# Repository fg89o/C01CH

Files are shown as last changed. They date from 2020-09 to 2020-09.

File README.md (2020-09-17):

# DomDom - C01CH

## ¿Qué es es el proyecto C01CH?

-----

Este proyecto nació con la intención de crear un controlador para pantallas de acuario. Después de revisar otros proyectos anteriores a este nos dimos cuenta que todos ellos o se quedaban incompletos o abarcaban mucho más que la pantalla. Por ello se decidió hacer un equipo lo más completo posible pero centrándonos únicamente en las necesidades para controlar una pantalla de acuario.

## Características principales

-----

* Equipo económico (coste inferior a 10€)
* Corriente de tensión hasta 24V.
* 1 canal dimeable por control de corriente.

   Esta característica significa que en vez de apagar y encender el led muy muy rápido como hacen otros controladores (control por PWM) nosotros controlamos el brillo del led mediante el control de corriente. Esto permite un brillo inferior pero teniendo el led encendido el 100% del tiempo.

   Por otra parte, esta característica permite ser el equipo compatible con el 100% de pantallas que trabajan con un voltaje igual o inferior a  24V.

* Monitorización del consumo y de la potencia.
* Ajuste manual de la potencia que se mantendrá incluso depués de apagar el equipo.
* Programación de potencia en función de la hora con hasta 50 puntos de programación.
* Servicio NTP para configurar la fecha, hora y ajuste de horario verano/invierno de forma automática.
* Control para un ventilador externo.
* Calculo en tiempo real del espectro de nuestra pantalla. (Siempre que configuremos el tipo de leds que estamos usando)
* Conexión mediante WIFI.
* Equipo actualizable de forma remota mediante WIFI.
* Servidor web integrado para configurar el equipo desde cualquier dispositivo, utilizando únicamente un navegador web.

-----

## Lista de materiales

-----

Pongo los links donde yo he comprado las cosas porque me ha parecido un buen vendedor pero cabe recalcar que no tengo ningún acuerdo con las tiendas que aparecen.

| Componente | Cantidad | Precio Total| link |
| --- | ---: | ---:| ---- |
| ESP32 Devkit-C de 36 pines  | 1 | 3.66€| [link](https://es.aliexpress.com/item/32807887667.html?spm=a2g0s.9042311.0.0.1f6c63c0jkFGcQ) |
| Mini DC-DC | 1 | 0.43€| [link](https://es.aliexpress.com/item/32649396601.html?spm=a2g0s.9042311.0.0.1f6c63c0jkFGcQ) |
| MOSFET PWM 400W 15A | 1 | 0.67€| [link](https://es.aliexpress.com/item/32803005422.html?spm=a2g0s.9042311.0.0.274263c0MQxfmC) |
| INA219 | 1 | 1.08€| [link](https://es.aliexpress.com/item/33025643671.html?spm=a2g0s.9042311.0.0.1f6c63c0jkFGcQ) |
| XL4015 | 1 | 0.91€| [link](https://es.aliexpress.com/item/4001118651312.html?spm=a2g0s.9042311.0.0.1f6c63c0jkFGcQ) |
| Resistencia 507Ohms | 1 | 0.005€| [link](https://es.aliexpress.com/item/32953278667.html?spm=a2g0s.9042311.0.0.274263c0MQxfmC) |
| Cables varios | 1 | 1  € | [link](https://es.aliexpress.com/item/32965231797.html?spm=a219c.12010615.8148356.1.6921396csAn5Dh)|
| DC Power pin hembra | 3 | 0.28€| [link](https://es.aliexpress.com/item/32973509798.html?spm=a2g0s.9042311.0.0.1f6c63c0jkFGcQ) |
| Caja 3D | 1 | 3€| [link](./STL%20Caja/XL4015) |
| Tornillo 12mm M3 y tuerca | 1 | 0.20€ | |
-----

## Esquema de conexiones

-----

Una imagen vale más que mil palabras...

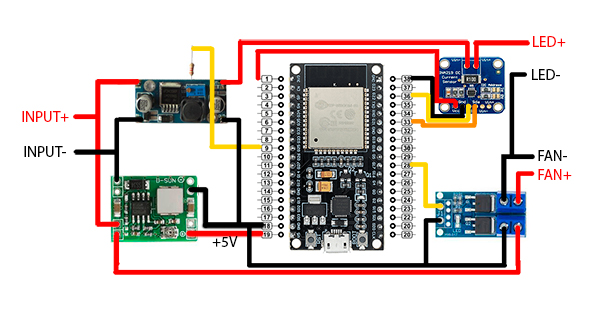
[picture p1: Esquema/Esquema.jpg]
Esquema


-----

## Firmware

-----

### Requisitos

* [NodeJS v12.18.3](https://nodejs.org/es/)
* [npm v6.14.6](https://www.npmjs.com/get-npm)
* [Visual studio code](https://code.visualstudio.com/download)
* [Platform IO](https://platformio.org/)
* [Vetur VS Code plugin](https://marketplace.visualstudio.com/items?itemName=octref.vetur)
* [C/C++ VS Code plugin](https://code.visualstudio.com/docs/languages/cpp)

### Compilacion

1. Tener instalados todos los requisitos mencionados anteriormente.
2. Clonar el repositorio
3. Abrir la carpeta "CH01CH UI" con el VS Code
4. Ejecutar en la terminal:

   ```javascript
   npm install
   ```

5. A continuación ejecutar:

   ```javascript
   npm run build
   ```

6. Abrir la carpeta "CH01CH fw" con el VS Code
7. Conectar el ESP32 por USB al ordenador
8. Ejecutar la opción "Task -> env:esp32dev -> Platform -> Upload Filesystem Image" o por terminal

   ```javascript
   platformio.exe run --target uploadfs --environment esp32dev
   ```

9. A) (opcional) Opcionalmente podemos modificar el fichero configuration.h con los datos de nuestra wifi para que se conecte directamente

   ```c
   // Define la red wifi a la que intetara conectase por defecto
   #define WIFI_STA_SSID_NAME "NOMBRE_DEL_WIFI"

   // Define el password de la red wifi por defecto
   #define WIFI_STA_PASSWORD "CONTRASEÑA"
   ```

10. B) Ejecutar la opción "Task -> General -> Upload" o por terminal

   ```javascript
   platformio.exe run --target upload
   ```

11. Comprobar que todo funciona correctamente:

* Si hemos configurado nuestro wifi en el paso 9.A solamente tendremos que acceder a http://C01CH.local.
* En caso de que no lo hayamos configurado debemos conectarnos al wifi creado por el equipo, que el SSID y será C01CH y después acceder a http://C01CH.local

# Soporte

Todo el que necesite soporte lo puede hacer bien a través de las issue de github de este proyecto o, los que dispongan de acceso, a través de este post en el que también se está siguiendo el proyecto.

# Agradecimientos

Muchas gracias a toda la gente que ha participado en este proyecto, bien con ideas, críticas que ayudan a crecer o de cualquier otro modo. En especial mencionar a todo el foro de [AcuariofiliaMadrid](https://acuariofiliamadrid.org/index.php) por el soporte dado y porque gracias al gran foro que mantienen he podido aprender los conocimientos necesarios para desarrollar satisfactoriamente este proyecto.

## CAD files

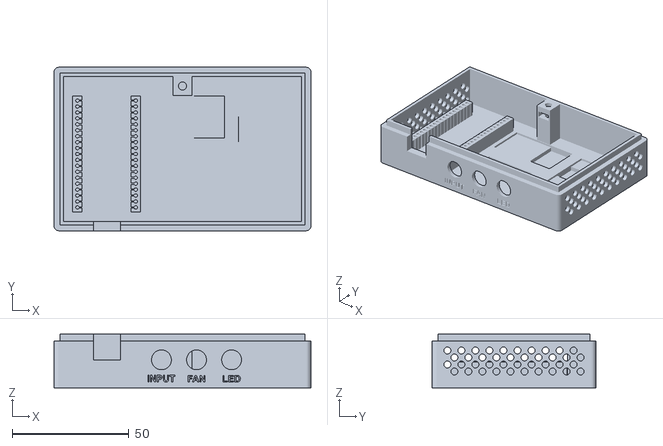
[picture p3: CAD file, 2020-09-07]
STL Caja/LM2596/Base LM2596.stl
110.0 x 70.0 x 23.0

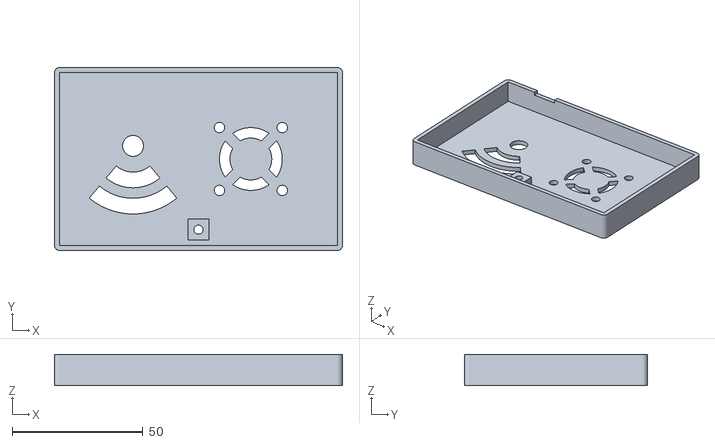
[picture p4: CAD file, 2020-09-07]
STL Caja/LM2596/Tapa LM2596.stl
110.0 x 70.0 x 12.0

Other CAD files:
STL Caja/XL4015/Base XL4015.stl
STL Caja/XL4015/Tapa XL4015.stl

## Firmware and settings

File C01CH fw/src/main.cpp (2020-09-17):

/**
 * DomDom Firmware
 * Copyright (c) 2020 DomDomFirmware
 *

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
 */

#include <Arduino.h>
#include <EEPROM.h>
#include <Wire.h>
#include "configuration.h"
#include "statusLedControl/statusLedControl.h"
#include "channel/channel.h"
#include "wifi/WiFi.h"
#include "rtc/rtc.h"
#include "webServer/webServer.h"
#include "EEPROMHelper.h"
#include "channel/ScheduleMgt.h"
#include "fan/fanControl.h"
#include "log/logger.h"

void initEEPROM()
{
  
  DomDomLogger.log(DomDomLoggerClass::LogLevel::info, "MAIN", "Iniciando EEPROM con %d bytes", EEPROM_SIZE+EEPROM_INA_SIZE);
  bool init = false;
  int err_count = 0;
  while(err_count<EEPROM_INIT_RETRIES && !init)
  {
      init = EEPROM.begin(EEPROM_SIZE+EEPROM_INA_SIZE);
      if (!init)
      {
          err_count++;
          Serial.print(".");
          delay(200);
      }
  }

  EEPROMCheck();

}

void setup()
{
  Serial.begin(BAUDRATE);

  DomDomLogger.log(DomDomLoggerClass::LogLevel::info, "MAIN", "C01CH Firmware | Copyright (c) 2020 Óscar Fernández");

  // Inicializamos la eeprom
  initEEPROM();

  // Inicializamos el control del led de estado
  DomDomStatusLedControl.begin();
  DomDomStatusLedControl.blinkDelay = 2000;
  DomDomStatusLedControl.blinkInfinite();
  DomDomStatusLedControl.blinkDelay = 1000;

  // Inicializa el wifi
  DomDomWifi.begin();
  // Si llegamos aqui y no estamos conectados resetamos en 5 segundos
  if (!DomDomWifi.isConnected())
  {
    int seg = 5;
    DomDomLogger.log(DomDomLoggerClass::LogLevel::error, "MAIN", "Equipo sin conexion. Se reiniciará en %d segundos!", seg);
    delay(seg * 1000);
    ESP.restart();
  }

  // Configuramos el RTC
  DomDomRTC.load();
  // Si tenemos conexion a internet inicamos todos los servicios
  if (DomDomWifi.getMode() == 1)
  {
    // Inicializacion del RTC
    DomDomRTC.begin();
  } else {
    DomDomLogger.log(DomDomLoggerClass::LogLevel::warn, "MAIN", "Equipo sin conexion no se establecera la hora RTC");
  }

  // Iniciamos el servidor web
  DomDomWebServer.begin();

  // configuramos el canal
  DomDomChannel.loadFromEEPROM();
 // Iniciamos el canal
  DomDomChannel.begin();  

  // Puntos de programacion
  DomDomScheduleMgt.load();
  
  // Iniciamos la programacion
  if (EEPROM.readBool(EEPROM_SCHEDULE_STATUS_ADDRESS))
  {
      DomDomScheduleMgt.begin();
  }else{
    DomDomChannel.setTargetmA(DomDomChannel.target_mA);
  }

  // Ventilador
  DomDomFanControl.begin();
}

void loop()
{

  /************************************************
   * 
   *  EN ESTE PROYECTO EL LOOP() ESTARA VACIO 
   *  YA QUE APROVECHAMOS LAS TASK PARA SACARLE
   *  EL MAXIMO PARTIDO A LOS DOS CORES DEL ESP.
   * 
   * *********************************************/

}

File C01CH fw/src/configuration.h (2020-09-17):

#pragma once

#ifndef DOMDOM_GLOBAL_CONFIGURACION_h
#define DOMDOM_GLOBAL_CONFIGURACION_h

#define DEBUG

// Datos del proyecto
#define PROJECT_VER     1.1
#define PROJECT_MODEL   "C01CH"

//===========================================================================
//============================ Serial Settings  =============================
//===========================================================================
// Define la velocidad de comunicación del puerto COM
#define BAUDRATE 9600

//===========================================================================
//============================ STATUS LED CONTROL  ==========================
//===========================================================================

#define LED_STATUS_RESOLUTION   10
#define LED_STATUS_CHANNEL      10
#define LED_STATUS_PIN          2
#define LED_STATUS_BLINK_DELAY  100

//===========================================================================
//============================ WIFI Settings  ===============================
//===========================================================================

// Define la red wifi a la que intetara conectase por defecto
#define WIFI_STA_SSID_NAME "" 

// Define el password de la red wifi por defecto
#define WIFI_STA_PASSWORD ""

// Numero de intentos para conectar el wifi
#define WIFI_NUM_RETRIES 3

// Tiempo de espera entre intentos
#define WIFI_CONNECTION_LATENCY 5000

// Nombre del AP que se creara para conectarse al equipo (32 digitos max.)
#define WIFI_AP_SSID_NAME "C01CH"

// Contraseña para el AP (entre 8 y 63 max.)
#define WIFI_AP_PASSWORD ""

// Numero maximo de conexiones al punto de acceso ( 4 max. )
#define WIFI_AP_MAX_CONNECTIONS 4

// Canal (entre 1 y 13)
#define WIFI_AP_CHANNEL 6

// Estado del ssid. 1 = HIDDEN ; 0 = BROADCAST
#define WIFI_AP_HIDDEN 0

//===========================================================================
//============================ mDNS SECTION =================================
//===========================================================================

#define MDNS_ENABLED 1

// Nombre mDNS para localizar el equipo
#define MDNS_HOSTNAME "C01CH"

//===========================================================================
//============================ CHANNELS SECTION =============================
//===========================================================================

#define CHANNEL_SIZE                    1
#define CHANNEL_RESOLUTION              8
#define CHANNEL_MAX_LEDS_CONFIG         10
#define CHANNEL_CURRENT_PIN             { 25 }
#define CHANNEL_BUS_REFRESH_INTERVAL    10000
#define CHANNEL_PERCENTAGE_MIN_STEP     5

//===========================================================================
//============================ FAN SECTION =============================
//===========================================================================
#define FAN_PWM_PIN                     17
#define FAN_PWM_RESOLUTION              10
#define FAN_PWM_CHANNEL                 12

//===========================================================================
//===================== RTC Y  NTP SECTION ==================================
//===========================================================================

#define RTC_BEGIN_ATTEMPS       3
#define RTC_BEGIN_ATTEMPS_DELAY 200

#define NTP_ENABLED             1
#define NTP_SERVERNAME          "pool.ntp.org"
#define NTP_TIMEZONE            "Europe/Madrid"
#define NTP_POSIX_TIMEZONE      "CET-1CEST,M3.5.0,M10.5.0/3"
#define NTP_DELAY_ON_FAILURE    10000
#define NTP_DELAY_ON_SUCCESS    3600000

//===========================================================================
//============================ EEPROM SECTION ===============================
//===========================================================================

#define EEPROM_SIZE                             EEPROM_FAN_ENABLED_ADDRESS
#define EEPROM_INIT_RETRIES                     10
#define EEPROM_INA_SIZE                         512

#define EEPROM_STA_SSID_NAME_ADDRESS            4
#define EEPROM_SSID_NAME_LENGTH                 32
#define EEPROM_STA_PASSWORD_ADDRESS             EEPROM_STA_SSID_NAME_ADDRESS + EEPROM_SSID_NAME_LENGTH
#define EEPROM_STA_PASSWORD_LENGTH              64

#define EEPROM_CHANNEL_FIRST_ADDRESS            EEPROM_STA_PASSWORD_ADDRESS +  EEPROM_STA_PASSWORD_LENGTH
#define EEPROM_CHANNEL_MEMORY_SIZE              16
#define EEPROM_CHANNEL_LED_MEMORY_SIZE          7
#define EEPROM_CHANNEL_LED_COUNT                10

#define EEPROM_MAX_SCHEDULE_POINTS              50
#define EEPROM_SCHEDULE_STATUS_ADDRESS          EEPROM_CHANNEL_FIRST_ADDRESS + EEPROM_CHANNEL_MEMORY_SIZE + (EEPROM_CHANNEL_LED_MEMORY_SIZE * EEPROM_CHANNEL_LED_COUNT)
#define EEPROM_SCHEDULE_FIRST_ADDRESS           EEPROM_SCHEDULE_STATUS_ADDRESS + 1
#define EEPROM_SCHEDULEPOINT_SIZE               5
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

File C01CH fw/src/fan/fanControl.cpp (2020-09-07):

/**
 * DomDom Firmware
 * Copyright (c) 2020 DomDomFirmware
 *

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
 */

#include "fanControl.h"
#include "configuration.h"
#include <EEPROM.h>
#include "../channel/channel.h"

DomDomFanControlClass::DomDomFanControlClass(){}

void DomDomFanControlClass::begin()
{
    if (!_started)
    {
        _started = true;

        pinMode(FAN_PWM_PIN, OUTPUT);

        min_pwm = 0;
        curr_pwm = 0;
        max_pwm = pow(2, FAN_PWM_RESOLUTION);

        min_channel_value = 0;
        max_channel_value = 100;

        // configure LED PWM functionalitites
        ledcSetup(FAN_PWM_CHANNEL, 50000, FAN_PWM_RESOLUTION);

        // attach the channel to be controlled
        ledcAttachPin(FAN_PWM_PIN, FAN_PWM_CHANNEL);

        // init PWM
        ledcWrite(FAN_PWM_CHANNEL, min_pwm); 

        xTaskCreate(
            this->fanTask,          /* Task function. */
            "fantTask",             /* String with name of task. */
            10000,                  /* Stack size in bytes. */
            NULL,                   /* Parameter passed as input of the task */
            1,                      /* Priority of the task. */
            NULL                    /* Task handle. */
        );
    }
}

void DomDomFanControlClass::end()
{
    if (_started)
    {
        _started = false;
    }
}

void DomDomFanControlClass::fanTask(void * parameter)
{
    while(DomDomFanControl.isStarted())
    {
        DomDomFanControl.update();
        vTaskDelay(5000 / portTICK_PERIOD_MS);
    }

    vTaskDelete(NULL);
}

void DomDomFanControlClass::update()
{
    if (DomDomChannel.started())
    {
        int rango_canal = DomDomChannel.maximum_mA - DomDomChannel.minimum_mA;
        int valor_canal = DomDomChannel.target_mA - DomDomChannel.minimum_mA;
        int porcentaje_canal = valor_canal * 100 / rango_canal;

        int rango_fan = max_channel_value - min_channel_value;
        int valor_fan = porcentaje_canal - min_channel_value;
        int porcentaje_fan = valor_fan * 100 / rango_fan;

        potencia = porcentaje_fan;

        int new_pwm = (max_pwm - min_pwm) * (porcentaje_fan / 100);
        if (new_pwm != curr_pwm)
        {
            Serial.printf("[FAN] Nuevo PWM: %d\r\n", new_pwm);
            setCurrentPWM(new_pwm);
        }
    }
    else
    {
       setCurrentPWM(min_pwm); 
    }
    
    
}

void DomDomFanControlClass::setCurrentPWM(uint16_t pwm)
{
    uint16_t max = pow(2,FAN_PWM_RESOLUTION);
    if (pwm > max)
    {
        Serial.printf("[FAN] ERROR: valor %hu pwm mayor que el maximo. Valor cambiado a %hu\n", pwm, max);
        pwm =  max;
    }

    if (pwm < 0)
    {
        Serial.printf("[FAN] ERROR: valor %d pwm menor que 0. Valor cambiado a 0\n", pwm);
        pwm = 0;
    }

    ledcWrite(FAN_PWM_CHANNEL, pwm);

    curr_pwm = pwm;
}

bool DomDomFanControlClass::save()
{
    int address = EEPROM_FAN_ENABLED_ADDRESS;
    EEPROM.writeBool(address, _started);
    address += 1;
    EEPROM.writeUShort(address, max_pwm);
    address += 2;
    EEPROM.writeUShort(address, min_pwm);
    address += 2;
    EEPROM.writeUShort(address, max_channel_value);
    address += 2;
    EEPROM.writeUShort(address, min_channel_value);
    address += 2;
    EEPROM.writeUShort(address, curr_pwm);

    return EEPROM.commit();
}

bool DomDomFanControlClass::load()
{
    if (isStarted())
    {
        end();
    }

    int address = EEPROM_FAN_ENABLED_ADDRESS;
    address+=1;
    max_pwm = EEPROM.readUShort(address);
    address += 2;
    min_pwm = EEPROM.readUShort(address);
    address += 2;
    max_channel_value = EEPROM.readUShort(address);
    address += 2;
    min_channel_value = EEPROM.readUShort(address);
    address += 2;
    setCurrentPWM(EEPROM.readUShort(address));

    if (EEPROM.readBool(EEPROM_FAN_ENABLED_ADDRESS))
    {
        begin();
    }

    return true;
}

#if !defined(NO_GLOBAL_INSTANCES)
DomDomFanControlClass DomDomFanControl;
#endif

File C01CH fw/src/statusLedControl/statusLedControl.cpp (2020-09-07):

/**
 * DomDom Firmware
 * Copyright (c) 2020 DomDomFirmware
 *

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
 */

#include "statusLedControl.h"
#include "configuration.h"

DomDomStatusLedControlClass::DomDomStatusLedControlClass()
{
    xMutex = xSemaphoreCreateMutex();
};

void DomDomStatusLedControlClass::begin()
{
    pinMode(LED_STATUS_PIN, OUTPUT);

    min_pwm = 0;
    max_pwm = pow(2, LED_STATUS_RESOLUTION);
    blinking = false;

    // configure LED PWM functionalitites
    ledcSetup(LED_STATUS_CHANNEL, 5000, LED_STATUS_RESOLUTION);
    
    // attach the channel to be controlled
    ledcAttachPin(LED_STATUS_PIN, LED_STATUS_CHANNEL);

    // init PWM
    ledcWrite(LED_STATUS_CHANNEL, max_pwm); 

}

void DomDomStatusLedControlClass::blinkInfinite()
{
    if (!isBlinking())
    {
        blinking = true;

        xTaskCreate(
            this->blinkTask,        /* Task function. */
            "Blink_Task",             /* String with name of task. */
            10000,                  /* Stack size in bytes. */
            NULL,                   /* Parameter passed as input of the task */
            1,                      /* Priority of the task. */
            NULL                    /* Task handle. */
        );
    }
    
}

void DomDomStatusLedControlClass::blink( int times)
{
    if (!isBlinking())
    {
        block();
        for (int i = 0; i < times; i++)
        {
            off();
            delay(LED_STATUS_BLINK_DELAY);
            on();
            delay(LED_STATUS_BLINK_DELAY);
            off();

            if (i < times)
            {
                delay(getDelay() / portTICK_PERIOD_MS);
            }
        }
        release();
    }
}

void DomDomStatusLedControlClass::blinkTask(void * parameter)
{
    DomDomStatusLedControl.block();
    while (DomDomStatusLedControl.isBlinking())
    {
        ledcWrite(LED_STATUS_CHANNEL, DomDomStatusLedControl.min_pwm);
        vTaskDelay(LED_STATUS_BLINK_DELAY / portTICK_PERIOD_MS);
        ledcWrite(LED_STATUS_CHANNEL, DomDomStatusLedControl.max_pwm);
        vTaskDelay(LED_STATUS_BLINK_DELAY / portTICK_PERIOD_MS);
        ledcWrite(LED_STATUS_CHANNEL, DomDomStatusLedControl.min_pwm);
        vTaskDelay(DomDomStatusLedControl.getDelay() / portTICK_PERIOD_MS);
    }
    DomDomStatusLedControl.release();

    vTaskDelete(NULL);
}

void DomDomStatusLedControlClass::block()
{
    xSemaphoreTake( xMutex, portMAX_DELAY );
}

void DomDomStatusLedControlClass::release()
{
    xSemaphoreGive( xMutex );
}

void DomDomStatusLedControlClass::on()
{
    blinking = false;
    block();
    Serial.println("Status led on");
    ledcWrite(LED_STATUS_CHANNEL, max_pwm);
    release();
}

void DomDomStatusLedControlClass::off()
{
    blinking = false;
    block();
    Serial.println("Status led off");
    ledcWrite(LED_STATUS_CHANNEL, min_pwm);
    release();
}

bool DomDomStatusLedControlClass::isBlinking()
{
    return blinking;
}

bool DomDomStatusLedControlClass::getDelay()
{
    return blinkDelay;
}

#if !defined(NO_GLOBAL_INSTANCES)
DomDomStatusLedControlClass DomDomStatusLedControl;
#endif

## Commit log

2020-07-12 commit inicial
    [configuration.h]
2020-08-14 Mejoras en la estabilidad de la salida para los led · WIP logger
2020-08-14 Añadido caja. Bugs
    [Base LM2596.stl, Base XL4015.stl, Tapa LM2596.stl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]
2020-08-15 Revertidos cambios del log por varios errores
    [WiFi.cpp, main.cpp]
2020-08-15 Cambios en la forma de estabilizar la salida de corriente.
2020-08-15 · Cambios en el calculo del porcentaje de los puntos de programacion. Se puede configurar el salta minimo del porcentaje usando CHANNEL_PERCENTAGE_MIN_STEP del fichero configuration.h. · Si el porcen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
    [configuration.h]
2020-08-15 · Cambios en el RTC para evitar la doble inicializacion. · Se añade marca de tiempo de la ultima peticion NTC · La tarea NTP se cambia a un diseño no bloqueante.
2020-08-16 Cambiada una comprobacion por la cual no se podia dejar la pantalla completamentamente apagada
2020-08-30 fix no se apagaba la pantalla por la histeresis. Añadido del valor actual del dac en el json de los canales.
    [channel.cpp, webServer.cpp]
2020-09-06 · Cambios en el canal para almacenar los valores maximo de voltios, amperios y watios. · Añadida ruta al webserver para resetear los valores maximos. · Añadidos valores maximos al json del webserver
    [channel.cpp, channel.h, webServer.cpp]
2020-09-06 · Añadidos ficheros de variables de entorno para facilitar la compilacion entre DEV y PROD · Reestructuración general del diseño · Añadidos valores maximos de voltaje, amperios y watios.
2020-09-09 · arreglado bug que no se enviaba el cambio de valor en el ajuste manual cuando se usaban los botones. · arreglado bug que no se enviaba el cambio de valor en el ajuste manual del ventilador. · aumen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
2020-09-09 · Cambiado DomDomChannel.Target_V por DomDomChannel.Maximum_V para reflejar mejor el valor almacenado. · Cambios en el metodo de estabilizar la salida de corriente para evitar parpadeos.
2020-09-17 version 2.0.2
    [configuration.h]

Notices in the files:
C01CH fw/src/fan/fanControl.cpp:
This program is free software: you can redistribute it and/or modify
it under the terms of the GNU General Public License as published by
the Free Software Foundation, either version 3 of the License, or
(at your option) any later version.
